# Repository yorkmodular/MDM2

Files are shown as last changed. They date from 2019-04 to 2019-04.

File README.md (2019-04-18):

## MDM2: Crap-fi drum machine module for Eurorack

This is the through-hole reincarnation of one of my old modules, the MDM (Modular Drum Machine) - I call it a crap-fi module because, let's face it, the sounds that you'll get out of it are rough, ready and pretty characterful.

The board features:

- Two tunable twin-T kick/bass drum oscillators - get everything from flabby kicks through to woodblocks and howling feedback. They can also be used as notch filters too, for added lulz.
- Two sets of tunable square-wave oscillators; kind of like a cut down version of the 808-style digital noise source; Schmitt trigger abuse for fun and profit.
- Two transistor VCAs - again, inspired by Roland's 808 design. Use the on-board oscillators plus an external envelope to get nice, clashy cymbal sounds.

Note that this isn't an ideal beginner's kit, although if you're patient and can hold a soldering iron at the right end then you can do it.

### Files

- `mdm2-bom.xlsx` - bill of materials (BOM) 
- `mdm2-schematic.png` - module schematic (this is what you're building ...)
- `mdm.mp3` and `mdm2-snippet.mp3` - a couple of sound samples; these are representative of what the module can sound like; how it ultimately turns out depends on how you build it.

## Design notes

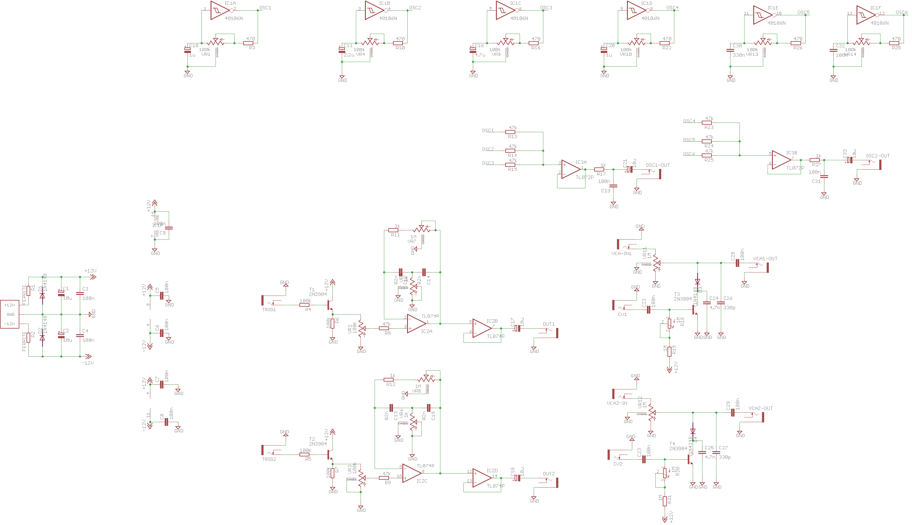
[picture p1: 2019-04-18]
mdm2-schematic.png

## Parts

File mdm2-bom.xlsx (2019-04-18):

Qty | Value | Device | Package | Parts | Description
1 | 100k | 9MM_SNAP-IN_POT_ | 9MM_SNAP-IN_POT | VR2 | 9mm vertical snap-in pot, Alpha / Panasonic style
7 | 100k | 9MM_SNAP-IN_POT_CHASSIS | 9MM_SNAP-IN_POT | VR1, VR3, VR4, VR9, VR10, VR13, VR14 | 9mm vertical snap-in pot, Alpha / Panasonic style, with a connection to the metal chassis for grounding
4 | 100k | R-EU_0207/2V | 0207/2V | R4, R5, R6, R7 | RESISTOR, European symbol
8 | 100n | C-EU025-025X050 | C025-025X050 | C3, C4, C5, C6, C7, C8, C9, C22 | CAPACITOR, European symbol
6 | 100n | C-EU050-025X075 | C050-025X075 | C19, C23, C28, C29, C31, C32 | CAPACITOR, European symbol
6 | 10u | CPOL-EUE2.5-5 | E2,5-5 | C1, C2, C17, C18, C21, C33 | POLARIZED CAPACITOR, European symbol
4 | 1M | 9MM_SNAP-IN_POT_CHASSIS | 9MM_SNAP-IN_POT | VR7, VR8, VR11, VR12 | 9mm vertical snap-in pot, Alpha / Panasonic style, with a connection to the metal chassis for grounding
2 | 1M | R-EU_0207/2V | 0207/2V | R19, R21 | RESISTOR, European symbol
2 | 1M | R-TRIMM3296W | RTRIM3296W | R18, R20 | Trimm resistor
4 | 1N4148 | DIODE-D-2.5 | D-2.5 | D1, D2, D3, D4 | DIODE
2 | 1k | 9MM_SNAP-IN_POT_CHASSIS | 9MM_SNAP-IN_POT | VR5, VR6 | 9mm vertical snap-in pot, Alpha / Panasonic style, with a connection to the metal chassis for grounding
4 | 1k | R-EU_0207/2V | 0207/2V | R11, R12, R17, R27 | RESISTOR, European symbol
2 | 1u | CPOL-EUE2.5-5 | E2,5-5 | C10, C20 | POLARIZED CAPACITOR, European symbol
1 | 2.2u | CPOL-EUE2.5-5 | E2,5-5 | C11 | POLARIZED CAPACITOR, European symbol
4 | 2N3904 | 2N3904 | TO92 | T1, T2, T3, T4 | NPN TRANSISTOR
1 | 330n | C-EU050-025X075 | C050-025X075 | C30 | CAPACITOR, European symbol
2 | 330p | C-EU025-025X050 | C025-025X050 | C26, C27 | CAPACITOR, European symbol
2 | 4.7n | C-EU025-025X050 | C025-025X050 | C24, C25 | CAPACITOR, European symbol
1 | 4.7u | CPOL-EUE2.5-5 | E2,5-5 | C16 | POLARIZED CAPACITOR, European symbol
1 | 40106N | 40106N | DIL14 | IC1 | Hex SCHMITT TRIGGER
6 | 470 | R-EU_0207/2V | 0207/2V | R3, R10, R16, R22, R26, R28 | RESISTOR, European symbol
8 | 47k | R-EU_0207/2V | 0207/2V | R8, R9, R13, R14, R15, R23, R24, R25 | RESISTOR, European symbol
4 | 82n | C-EU050-025X075 | C050-025X075 | C12, C13, C14, C15 | CAPACITOR, European symbol
1 | EURO_POWER_LOCK | EURO_POWER_LOCK | EURO_PWR_HEADER_LOCK | LOCK1
2 | FERRITE | R-EU_0207/2V | 0207/2V | R1, R2 | RESISTOR, European symbol
12 | THONKICONNNEW | THONKICONNNEW | WQP-PJ301M-12_JACK | CV1, CV2, OSC1-OUT, OSC2-OUT, OUT1, OUT2, TRIG1, TRIG2, VCA-IN1, VCA1-OUT, VCA2-IN, VCA2-OUT | 3.5mm socket for Eurorack modular synths
1 | TL072P | TL072P | DIL08 | IC3 | OP AMP
1 | TL074P | TL074P | DIL14 | IC2 | OP AMP
 |  |  |  | C10, C11, C16, C20, C30 and C32 control the base frequency of the six square-wave oscillators. The
 |  |  |  | values are not set in stone so feel free to experiment – higher capacitances will yield a lower base frequency.
 |  |  |  | If you want a gated LFO-style effect, use 22uF or larger, otherwise anything less than 10uF works fine.
 |  |  |  | Trimmers R18 and R20 control the VCA offset – twiddle with them until you get a sound you like.
 |  |  |  | C12/C14 and C13/C15 control the frequency of the two twin-T oscillator circuits – 82nF will get you a good, beefy kick
 |  |  |  | sound with both tuning pots fully counter-clockwise (100nF also works) – lower capacitances will yield
 |  |  |  | higher frequencies. For a wood block-ish effect, try 33nF or 47nF – any less is not recommended. Note that the
 |  |  |  | two capacitors in the twin-T filters should have the same value.

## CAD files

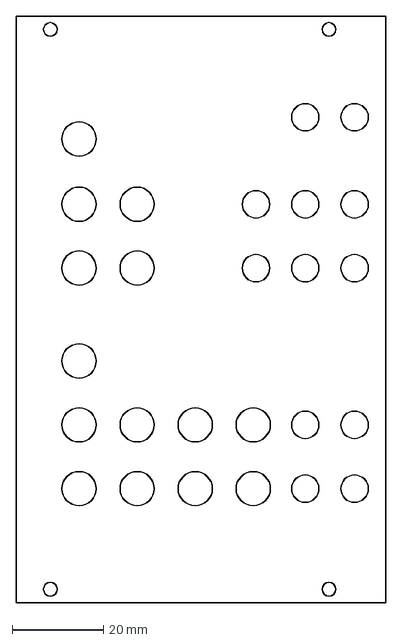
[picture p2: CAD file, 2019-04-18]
mdm2-blank.dxf
80.9 x 128.4 mm

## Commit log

2019-04-18 Panel files
    [mdm2-blank.dxf, mdm2-lettered.dxf]
2019-04-26 Modified design
    [mdm2-lettered.dxf]
2019-05-01 Fix layout of panel - transposed CV and SIGNAL inputs for VCAs
    [mdm2-lettered.dxf]
